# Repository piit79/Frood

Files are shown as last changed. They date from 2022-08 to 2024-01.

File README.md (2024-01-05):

# The Frood

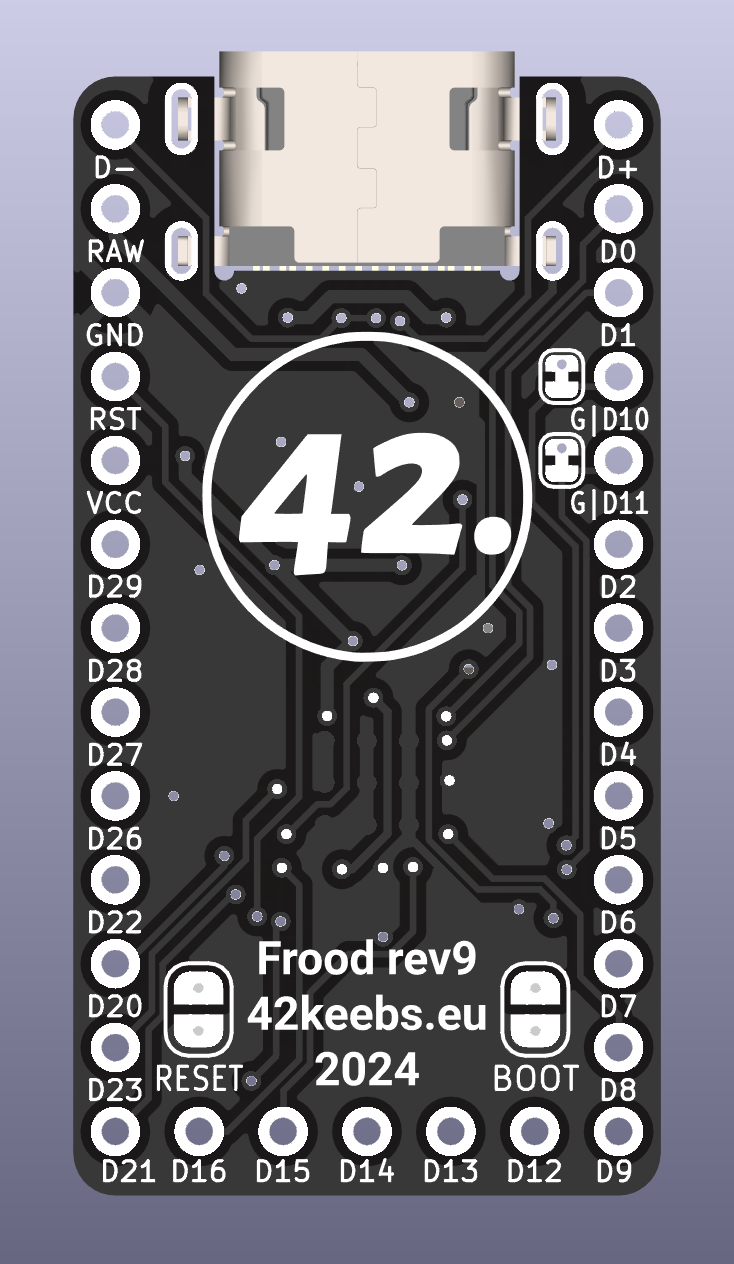
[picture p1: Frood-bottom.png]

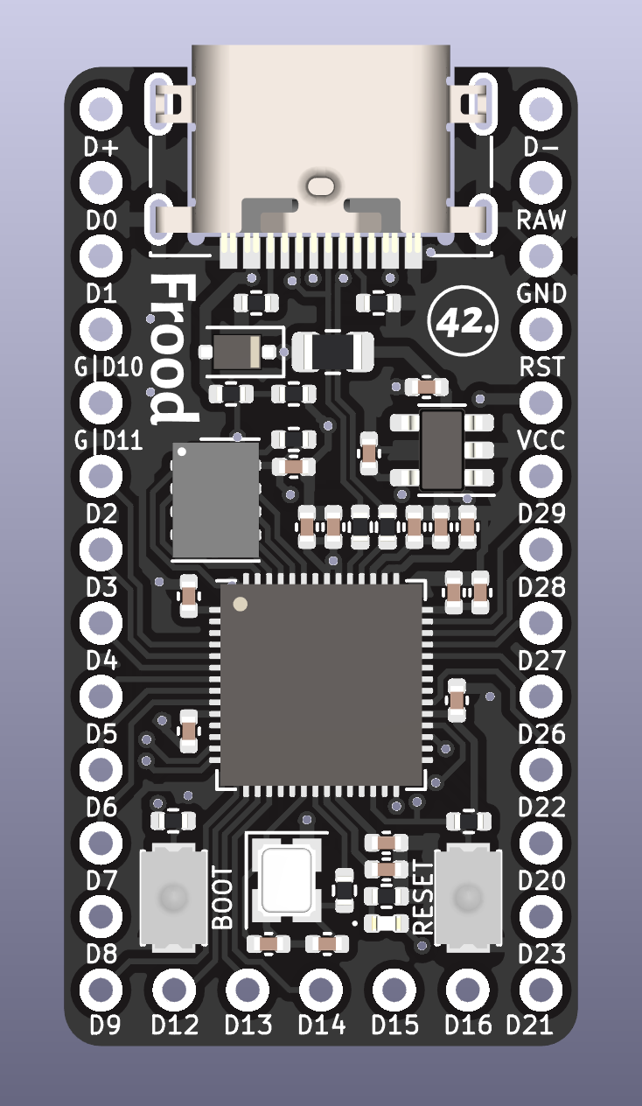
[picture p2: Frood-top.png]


The Frood is a high-performance _and_ affordable Pro Micro drop-in replacement based on a Raspberry Pi RP2040. It is physically and electrically compatible with Elite-C/nice!nano as much as possible.

It follows the [SparkFun Pro Micro RP2040](https://www.sparkfun.com/products/18288) pinout with 5 more pins (GPIO12-GPIO16) added along the bottom edge (like on Elite-C), and USB data lines broken out in the top corners.

## Features

* Powerful dual-core Raspberry Pi RP2040 MCU
* 4 MB of on-board flash memory
* Only 3.2 mm thick thanks to a mid-mounted USB-C socket
* 500 mA linear regulator and resettable fuse
* Combined Pro Micro / Elite-C / nice!nano / SparkFun Pro Micro RP2040 compatible pinout
* 5 more I/O pins (GPIO12-GPIO16) added along the bottom edge
* 2 more I/O pins (GPIO10, GPIO11) can be converted from left-hand side GND pins by cutting a jumper
* 23-25 total available digital pins for a maximum of 11x12 = 132 (or even 12x13 = 156) switches
* 4 pins configurable as analogue inputs
* USB D+/D- broken out for use with an external USB socket/daughterboard
* USB power sensing on GPIO19 for split keyboard side detection
* UF2 bootloader for drag & drop programming with no extra software required
* Orange indicator LED on pin GPIO17
* Now with [official CircuitPython support](https://circuitpython.org/board/42keebs_frood/)

## Availability

The Frood is available from [42keebs.eu](https://42keebs.eu/shop/parts/controllers/frood-rp2040-pro-micro-controller/).

## Revision history

**Rev9** (03/01/2024)
* Allows converting left-hand side GND pins into GPIO pins (GPIO10, GPIO11) by cutting PCB jumpers
* VBUS IN/OUT solder jumper dropped, the RAW pin is now connected to VBUS after a Schottky diode/input of linear regulator before a resettable fuse
* Uses a different (but equivalent) USB-C socket due to component shortage
* Routing and silkscreen tweaks/improvements

**Rev8** (10/10/2023)
* Add a 2-way solder jumper to select VBUS OUT or VBUS IN on the RAW pin
* Use orange indicator LED again

**Rev7** (23/06/2023)
* Use a different 4 MB flash chip (Winbond W25Q32JVUUIQ) which will hopefully not need a special config
* Use a higher-quality Panasonic reset/boot switches
* Some routing tweaks
* Bug: uses red indicator LED by mistake

**Rev6** (28/12/2022)
* Use a 4 MB (32 Mbit) flash chip (needs a special configuration in QMK `config.h`: `#define RP2040_FLASH_GD25Q64CS`)
* Tweak a few tracks

**Rev5** (26/10/2022)
* Improve USB socket position to match nice!nano
* Add BOOT/RESET pads on the bottom of the PCB (when the buttons are not accessible)
* Use a smaller crystal to gain some valuable space
* Add an orange indicator LED on pin GPIO17 (inspired by the [0xB2](https://github.com/plut0nium/0xB2))

**Rev4** (28/09/2022) - **Confirmed working**
* Use a 2 MB flash with correct supply voltage rating
* Switch to GT-USB-7014C USB-C socket and a standard 1.6 mm PCB
* Improve pin labels
* Improve routing

**Rev3** (18/08/2022) - **DO NOT USE!**
* Rename to "Frood"
* Use HRO-TYPE-C-31-M-14 for a fully mid-mounted socket with a 1.0 mm PCB
* Use 500 mA fuse instead of 350 mA one
* Improve layout (move USB termination resistors closer to MCU)
* Still uses the same flash chip with an incorrect supply voltage (1.8-2.6 V)

**Rev2** (16/08/2022) - **DO NOT USE!**
* Rename to "PiMicro2040"
* Fix crystal routing
* Use Elite-C/nice!nano-like outline
* Use mid-mounted USB-C connector (HRO-TYPE-C-31-M-13)
* Use a "standard" Sparkfun Pro Micro-compatible pinout
* Add 350 mA resettable fuse
* Add VBUS sensing
* Break-out USB data lines
* Contains a critical error - flash chip with an incorrect supply voltage (1.8-2.6 V)

**Rev1** (08/08/2022) - **DO NOT USE!**
* Initial version with a top-mounted USB-C socket, a shorter outline and a custom pinout
* Contains a critial error - incorrect crystal routing due to a mismatch between a 2-pin symbol and a 4-pin footprint

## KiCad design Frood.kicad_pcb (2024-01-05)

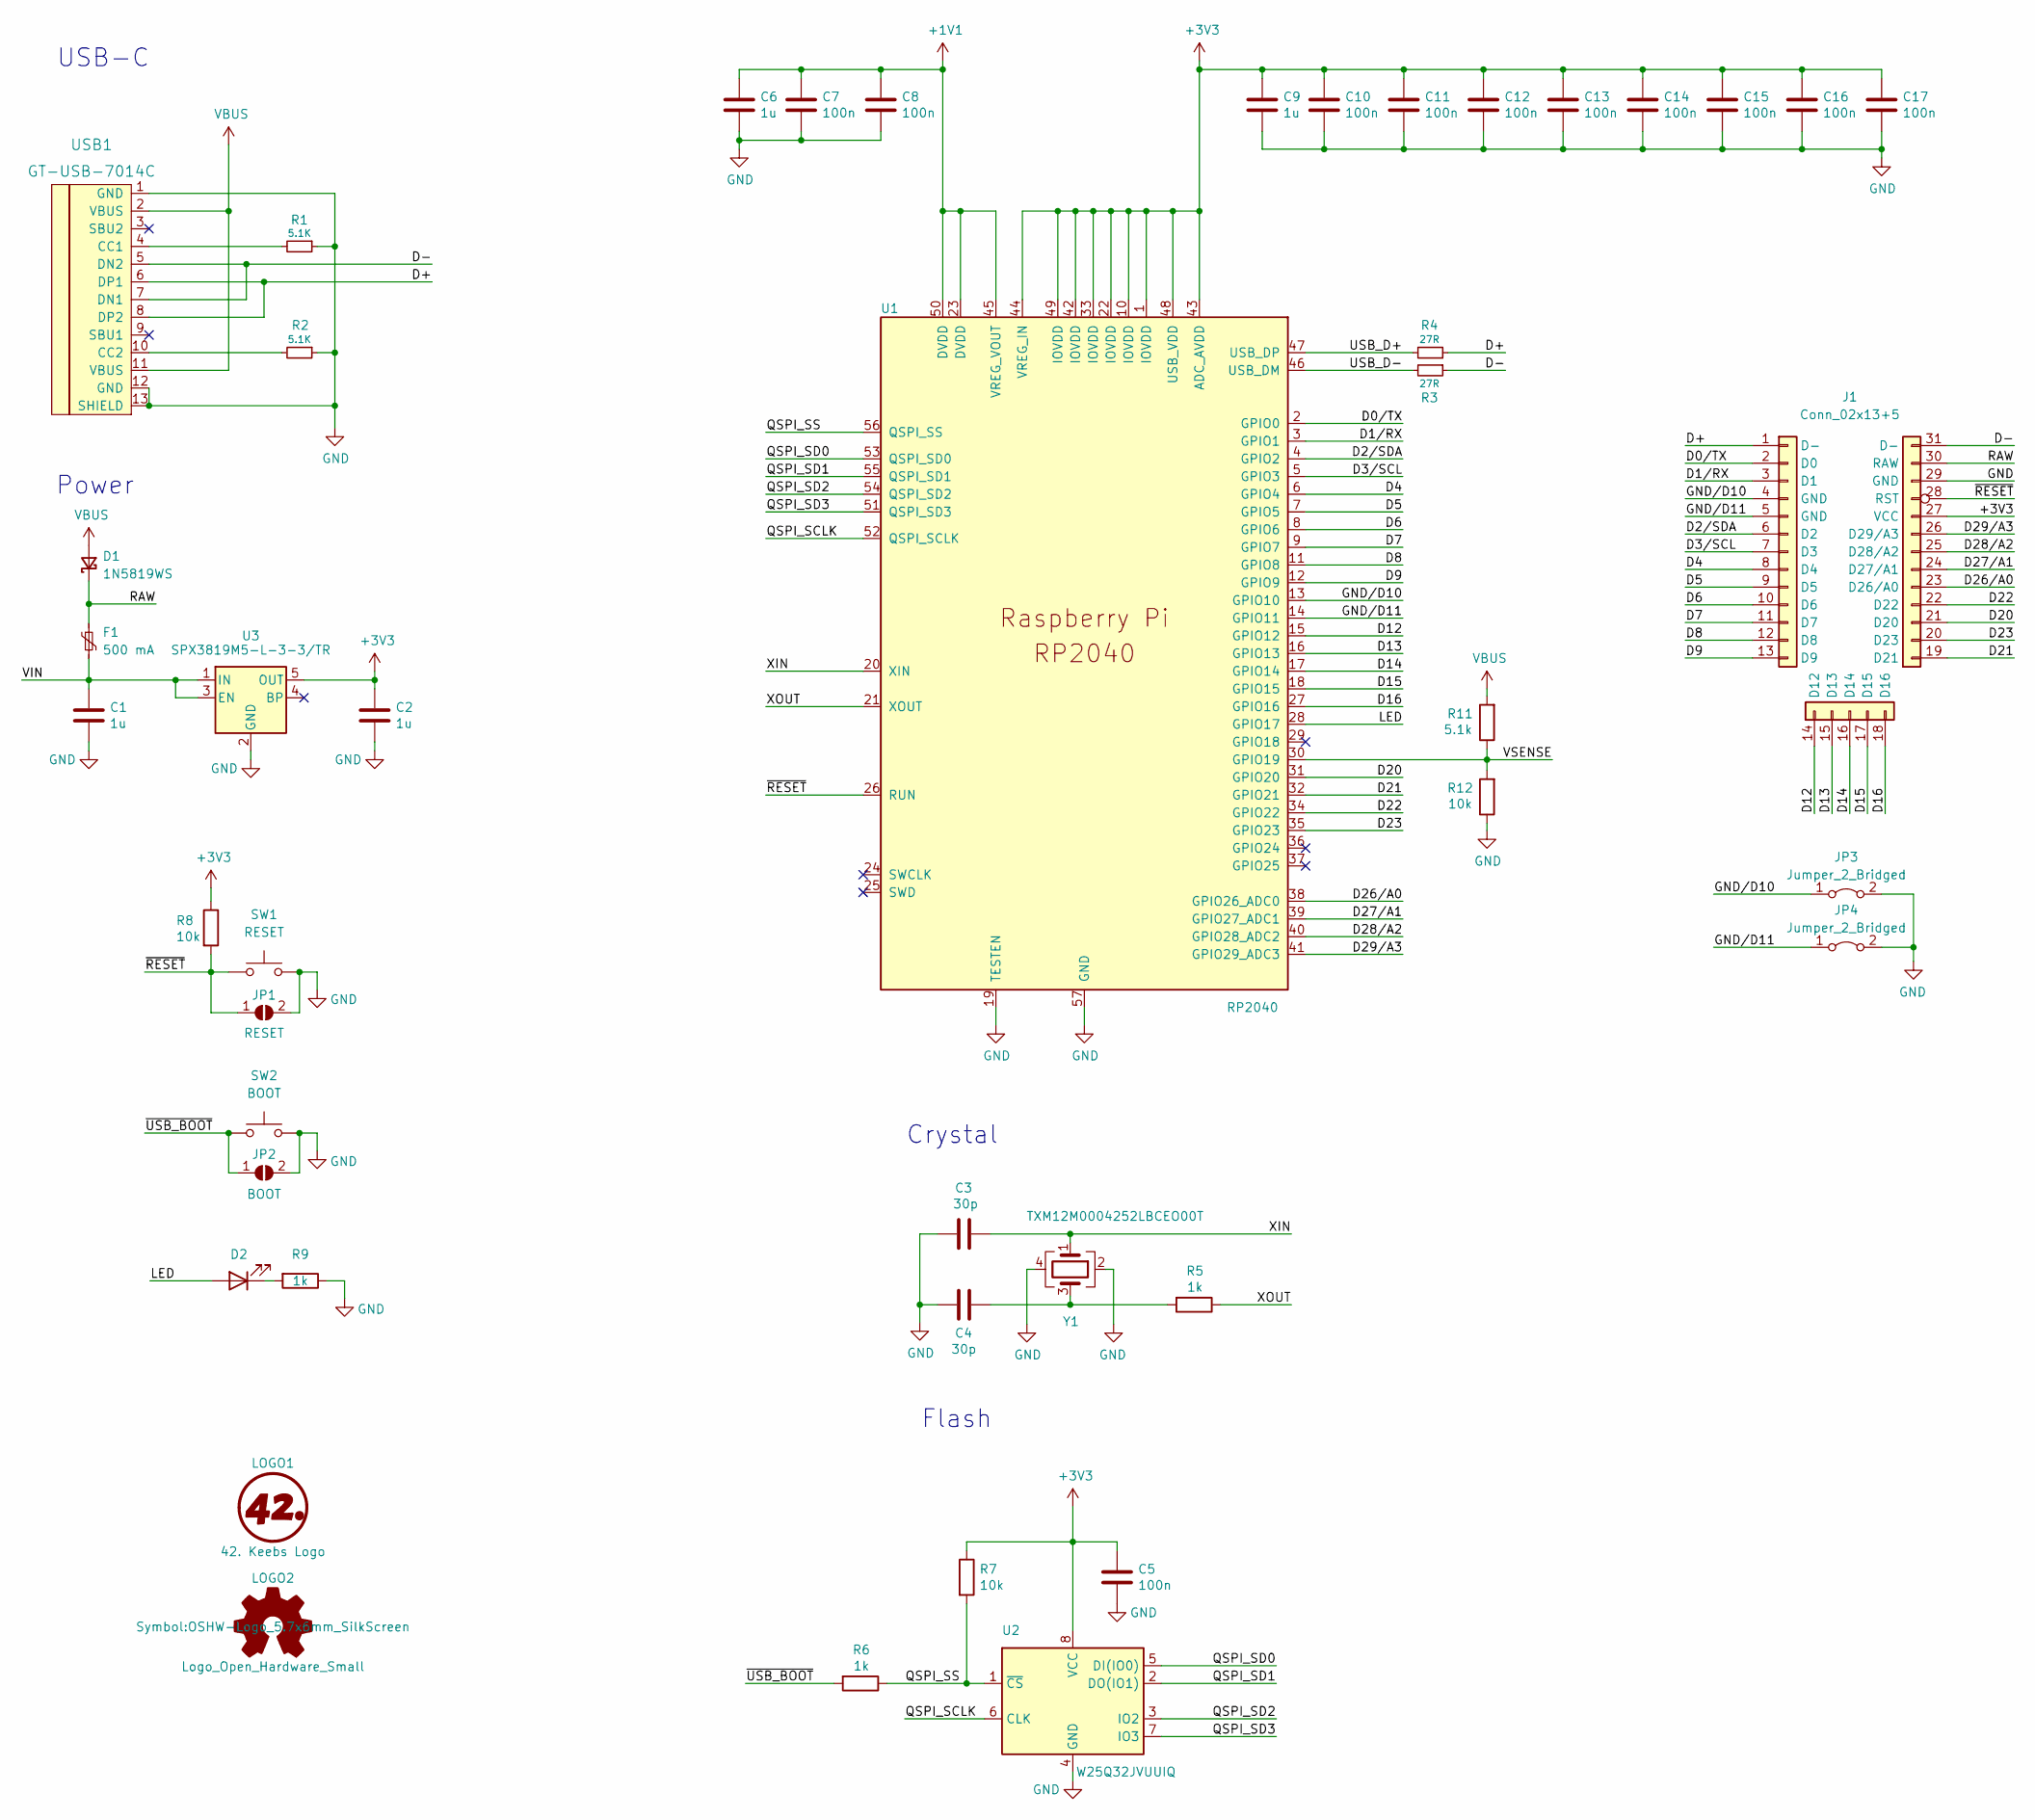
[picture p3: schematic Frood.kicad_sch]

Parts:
C1, C2, C6, C9: 1u; C_0402_1005Metric
C3, C4: 30p; C_0402_1005Metric
C5, C7, C8, C10, C11, C12, C13, C14, C15, C16, C17: 100n; C_0402_1005Metric
D1: 1N5819WS; D_SOD-323F
D2: LED; LED_0402_1005Metric
F1: 500 mA; R_0805_2012Metric
J1: Conn_02x13+5; PinHeader_2x13+5_P2.54mm_Vertical_Frood
JP1: RESET; SolderJumper-2_P1.3mm_Open_RoundedPad1.0x1.5mm
JP2: BOOT; SolderJumper-2_P1.3mm_Open_RoundedPad1.0x1.5mm
JP3, JP4: Jumper_2_Bridged; SolderJumper-2_P0.8mm_Bridged_RoundedPad0.5x1mm
LOGO1: 42. Keebs Logo; 42Keebs-icon-10mm-SilkS
LOGO2: Logo_Open_Hardware_Small; OSHW-Logo_5.7x6mm_SilkScreen
R1, R2: 5.1K; R_0402_1005Metric
R3, R4: 27R; R_0402_1005Metric
R5, R6, R9: 1k; R_0402_1005Metric
R7, R8, R12: 10k; R_0402_1005Metric
R11: 5.1k; R_0402_1005Metric
SW1: RESET; SW_SPST_CK_KXT3
SW2: BOOT; SW_SPST_CK_KXT3
U1: RP2040; RP2040-QFN-56
U2: W25Q32JVUUIQ; USON-8_4x3mm_P0.8mm
U3: SPX3819M5-L-3-3/TR; SOT-23-5
USB1: GT-USB-7014C; Molex-216990_GCT-USB45xx_HRO-TYPE-C-31-M-13x-Frood
Y1: TXM12M0004252LBCEO00T; Crystal_SMD_2520-4Pin_2.5x2.0mm

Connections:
+1V1: C6.1, C7.1, C8.1, U1.23 (DVDD), U1.45 (VREG_VOUT), U1.50 (DVDD)
+3V3: C2.1, C5.1, C9.1, C10.1, C11.1, C12.1, C13.1, C14.1, C15.1, C16.1, C17.1, J1.27 (VCC), R7.1, R8.1, U1.1 (IOVDD), U1.10 (IOVDD), U1.22 (IOVDD), U1.33 (IOVDD), U1.42 (IOVDD), U1.43 (ADC_AVDD), U1.44 (VREG_IN), U1.48 (USB_VDD), U1.49 (IOVDD), U2.8 (VCC), U3.5 (OUT)
/D0/TX: J1.2 (D0), U1.2 (GPIO0)
/D1/RX: J1.3 (D1), U1.3 (GPIO1)
/D2/SDA: J1.6 (D2), U1.4 (GPIO2)
/D3/SCL: J1.7 (D3), U1.5 (GPIO3)
/D4: J1.8 (D4), U1.6 (GPIO4)
/D5: J1.9 (D5), U1.7 (GPIO5)
/D6: J1.10 (D6), U1.8 (GPIO6)
/D7: J1.11 (D7), U1.9 (GPIO7)
/D8: J1.12 (D8), U1.11 (GPIO8)
/D9: J1.13 (D9), U1.12 (GPIO9)
/D12: J1.14 (D12), U1.15 (GPIO12)
/D13: J1.15 (D13), U1.16 (GPIO13)
/D14: J1.16 (D14), U1.17 (GPIO14)
/D15: J1.17 (D15), U1.18 (GPIO15)
/D16: J1.18 (D16), U1.27 (GPIO16)
/D20: J1.21 (D20), U1.31 (GPIO20)
/D21: J1.19 (D21), U1.32 (GPIO21)
/D22: J1.22 (D22), U1.34 (GPIO22)
/D23: J1.20 (D23), U1.35 (GPIO23)
/D26/A0: J1.23 (D26/A0), U1.38 (GPIO26_ADC0)
/D27/A1: J1.24 (D27/A1), U1.39 (GPIO27_ADC1)
/D28/A2: J1.25 (D28/A2), U1.40 (GPIO28_ADC2)
/D29/A3: J1.26 (D29/A3), U1.41 (GPIO29_ADC3)
/D+: J1.1 (D-), R4.1, USB1.6 (DP1), USB1.8 (DP2)
/D-: J1.31 (D-), R3.1, USB1.5 (DN2), USB1.7 (DN1)
/GND/D10: J1.4 (GND), JP3.1 (A), U1.13 (GPIO10)
/GND/D11: J1.5 (GND), JP4.1 (A), U1.14 (GPIO11)
/LED: D2.2 (A), U1.28 (GPIO17)
/QSPI_SCLK: U1.52 (QSPI_SCLK), U2.6 (CLK)
/QSPI_SD0: U1.53 (QSPI_SD0), U2.5 (DI(IO0))
/QSPI_SD1: U1.55 (QSPI_SD1), U2.2 (DO(IO1))
/QSPI_SD2: U1.54 (QSPI_SD2), U2.3 (IO2)
/QSPI_SD3: U1.51 (QSPI_SD3), U2.7 (IO3)
/QSPI_SS: R6.1, R7.2, U1.56 (QSPI_SS), U2.1 (~CS)
/RAW: D1.1 (K), F1.1, J1.30 (RAW)
/USB_D+: R4.2, U1.47 (USB_DP)
/USB_D-: R3.2, U1.46 (USB_DM)
/VIN: C1.1, F1.2, U3.1 (IN), U3.3 (EN)
/VSENSE: R11.1, R12.2, U1.30 (GPIO19)
/XIN: C3.1, U1.20 (XIN), Y1.1
/XOUT: R5.1, U1.21 (XOUT)
/~RESET: J1.28 (RST), JP1.1 (A), R8.2, SW1.1, U1.26 (RUN)
/~USB_BOOT: JP2.1 (A), R6.2, SW2.1
GND: C1.2, C2.2, C3.2, C4.2, C5.2, C6.2, C7.2, C8.2, C9.2, C10.2, C11.2, C12.2, C13.2, C14.2, C15.2, C16.2, C17.2, J1.29 (GND), JP1.2 (B), JP2.2 (B), JP3.2 (B), JP4.2 (B), R1.1, R2.1, R9.1, R12.1, SW1.2, SW2.2, U1.19 (TESTEN), U1.57 (GND), U2.4 (GND), U3.2 (GND), USB1.1 (GND), USB1.12 (GND), USB1.13 (SHIELD), Y1.2, Y1.4
unnamed: C4.1, R5.2, Y1.3
unnamed: D2.1 (K), R9.2
unnamed: R1.2, USB1.4 (CC1)
unnamed: R2.2, USB1.10 (CC2)
VBUS: D1.2 (A), R11.2, USB1.2 (VBUS), USB1.11 (VBUS)

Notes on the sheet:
Power
Crystal
Flash
USB-C

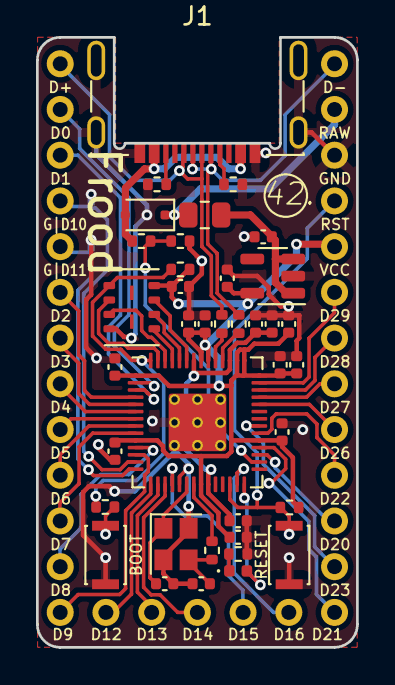
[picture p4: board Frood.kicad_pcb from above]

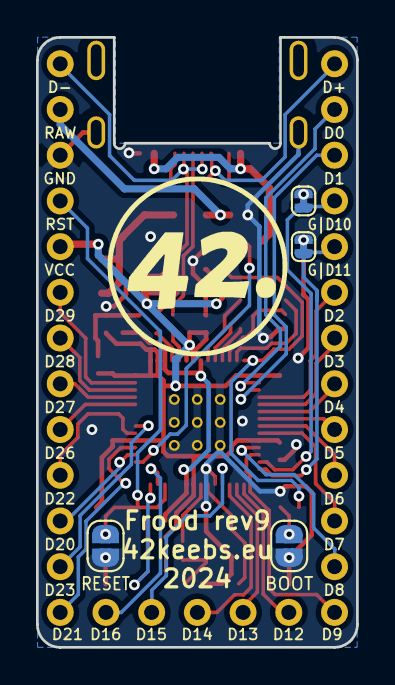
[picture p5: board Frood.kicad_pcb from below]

Board: 2 copper layers, 17.8 x 33.9 mm, 44 parts (5 on the bottom side), 51 nets.

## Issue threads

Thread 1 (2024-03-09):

Specific PINOUT example

kunsteak, 2024-03-09:
Love this board and am grateful for the sleek and simple design. It would be even better if you could make a mock QMK keyboard folder utilising all of the 23 pins and add it to this repo for reference. Nothing too fancy, or logical, just to show how one would have to write the info.json for both direct and matrix wiring.

kunsteak, 2024-03-09:
I opened this issue because I thought it'd be more intuitive for people just getting into the hobby to find and figure out how to do things. This is the first rp2040 chip that I am working with and when I'm done figuring everything out I might upload some examples for how to use the Frood myself.

kunsteak, 2024-03-13:
I've successfully configured my custom [QAZ](https://github.com/kunsteak/vial-qmk/tree/vial/keyboards/handwired/qaz) keyboard to work with the Frood.

Closed 2024-03-13.

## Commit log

2022-07-29 Add 42. Keebs KiCad library as a submodule
2022-07-29 Add the RP2040_minimal library
    Courtesy of https://datasheets.raspberrypi.com/rp2040/Minimal-KiCAD.zip
2022-07-29 Add ai03's Type-C.pretty KiCad library as a submodule
2022-08-08 Initial version with a top-mounted USB-C socket
    [promicro2040.kicad_pcb, promicro2040.kicad_sch]
2022-08-16 Update 42. Keebs KiCad library
2022-08-16 Bulk update to rev2
    * Rename to PiMicro2040
    * Fix critical error cause by 2-pin crystal symbol vs. 4-pin footprint
    * Use Elite-C/nice\!nano-like outline
    * Use mid-mounted USB-C connector
    * Use a "standard" Sparkfun Pro Micro-compatible pinout
    * Add 350 mA resettable fuse
    * Add VBUS sensing
    * Break-out USB data lines
    [pimicro2040.kicad_pcb, pimicro2040.kicad_sch, promicro2040.kicad_pcb]
2022-08-17 Rev3 update
    * Use HRO-TYPE-C-31-M-14
    * Use 500 mA fuse instead of 350 mA one
    * Improve layout (move USB termination resistors closer to MCU)
    [pimicro2040.kicad_pcb, pimicro2040.kicad_sch]
2022-08-17 Rename to Frood; use a 500 mA regulator; update README
    [Frood.kicad_pcb, Frood.kicad_sch]
2022-08-17 Fix the USB-C socket value; Use an in-stock 27R resistor
    [Frood.kicad_pcb, Frood.kicad_sch]
2022-08-18 Drop the forced I2C pull-up resistors; Add flash 3D model
    [Frood.kicad_pcb, Frood.kicad_sch]
2022-08-18 Move pin labels further inwards
    [Frood.kicad_pcb]
2022-09-18 Update the 42. Keebs KiCad library
2022-09-28 Rev4 update
    * Use correctly-specced 16 Mbit QSPI flash
    * Switch to fully mid-mounted GT-USB-7014C USB-C socket and 1.6 mm PCB
    * Improve pin labels
    * Improve routing
    * Update the README with version history
    [Frood.kicad_pcb, Frood.kicad_sch]
2022-10-07 Improve USB socket position; add boot/reset pads on the bottom
    [Frood.kicad_pcb, Frood.kicad_sch]
2022-10-25 Rev5 update
    * Use a smaller crystal to get some valuable space back
    * Add an orange indicator LED on pin GPIO17
    [Frood.kicad_pcb, Frood.kicad_sch]
2022-10-25 Fix DRC violations when using round tracks
    [Frood.kicad_pcb]
2023-06-27 Rev6 update
    * Use a 4 MB (32 Mb) flash chip instead
    * Minor routing fine-tuning
    [Frood.kicad_pcb, Frood.kicad_sch]
2023-06-27 Rev7 update
    * Use a Winbond 4 MB flash chip
    * Use higher quality Panasonic reset/boot switches
    * A few routing tweaks
    [Frood.kicad_pcb, Frood.kicad_sch]
2023-10-10 Rev8 update
    * Add a 2-way solder jumper to select VBUS OUT or VBUS IN on the RAW pin
    * Use orange indicator LED again
    [Frood.kicad_pcb, Frood.kicad_sch]
2024-01-05 Rev9 update
    * Allows converting left-hand side GND pins into GPIO10,11 pins
    * Drop VBUS IN/OUT solder jumper, RAW pin now connected between the Schottky and fuse/regulator
    * Uses a different (but equivalent) USB-C socket
    * Routing and silkscreen tweaks/improvements
    [Frood.kicad_pcb, Frood.kicad_sch]
